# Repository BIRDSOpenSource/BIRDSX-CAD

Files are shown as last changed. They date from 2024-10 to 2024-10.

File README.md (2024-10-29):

<div align="center">
  <a href="https://lean-sat.org/opensource/">
  
  </a>
</div> 

<div align="center">
  birds x
</div>

# BIRDSX-CAD
Documentation for the structure files of the BIRDSX Satellite.

## About the BIRDSX Program:

The Mission Statement of the Project is:

> “The goal of our project is to bring diversity to the space sector and democratize the usage of space.”

The project is led by the Kyushu Institute of Technology in Japan and involves students from more than 13 countries.

Satellite Names: Dragonfly (Japan), 

Stakeholders:  Our stakeholders are the Kyushu Institute of Technology (Kyutech) and the Association for Radio Digital Communications (ARDC).

Project duration: 2023-2025

CubeSat: 2U (20x10x10) cm3

Weight: 1.758kg

Launch Date: 21st February 2025

BIRDS-X project is a 2U CubeSat dedicated to amateur radio communication.

## Organisation structure

```bash

├── BIRDSX-CAD
│   ├── Assembly Dragonfly step.zip
│   ├── Screw_Procurement list_v2 (version 1).xlsx
│   ├── Satellite part Stresses 2.xlsx
│   ├── BIRDSX- Structure
│   │   ├── CAD
│   │   │   ├── 0_2U_STD
│   │   │   ├── 1_2U_STD
│   │   │   ├── 2_2U_STD
│   │   │   ├── 3_2U_STD
│   │   │   ├── 4_2U_STD
│   │   │   ├── 5_2U_STD
│   │   │   ├── 6_2U_STD
│   │   │   ├── 7_2U_STD
│   │   │   ├── 8_2U_STD
│   │   │   ├── 9_2U_STD
│   │   ├── Drawings
│   │   │   ├── 0_2U_STD
│   │   │   ├── 1_2U_STD
│   │   │   ├── 2_2U_STD
│   │   │   ├── 3_2U_STD
│   │   │   ├── 4_2U_STD
│   │   │   ├── 5_2U_STD
│   │   │   ├── 6_2U_STD
│   │   │   ├── 7_2U_STD
│   │   │   ├── 8_2U_STD
│   │   │   ├── 9_2U_STD

```

## Features

## I like this project, can I help you?
You are welcome 🙂

* Give us a star ⭐
* Watch repository to be notified about updates 👀
* If you will find some errors, report them in Issues 🐞
* Try Birds designs on some real computer and let us know how it worked in Discussions. 💬
* We would greatly appreciate if you would also tell others about this ecosystem, it helps us to improve BIRDS Open Source. Thank you!
# BIRDSX-Source_Codes

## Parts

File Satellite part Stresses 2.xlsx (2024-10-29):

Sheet: Sheet1
Part | Material | Max Stress (Smax) (MPa) | Yield strength (MPa) | Ultimate Strength, Ftu(MPa) | MS (Yield) | MS (Ultimate) | Smax/Ftu [%] |  |  | Part | Material | Max Stress (Smax) (MPa) | Yield strength (MPa) | Ultimate Strength, Ftu(MPa) | MS (Yield) | MS (Ultimate) | Smax/Ftu [%] | Part | Material | Max Stress (Smax) (MPa) | Yield strength (MPa) | Ultimate Strength, Ftu(MPa) | MS (Yield) | MS (Ultimate) | Smax/Ftu [%]
 |  |  |  |  | 1.50 | 2.00 | <30 |  |  |  |  |  |  |  | 1.50 | 2.00 | <30 |  |  |  |  |  | 1.50 | 2.00 | <30
Structure-01 | A6061-T6 | 11.30 | 276.00 | 310.00 | 15.28 | 12.72 | 3.65 | 1.50 | 2.00 | Structure-01 | A6061-T6 | 9.76 | 276.00 | 310.00 | 17.84 | 14.87 | 3.15 | Structure-01 | A6061-T6 | 9.44 | 276.00 | 310.00 | 18.49 | 15.42 | 3.05
Structure-02 | A6061-T6 | 9.11 | 276.00 | 310.00 | 19.20 | 16.01 | 2.94 | 1.50 | 2.00 | Structure-02 | A6061-T6 | 7.86 | 276.00 | 310.00 | 22.40 | 18.71 | 2.54 | Structure-02 | A6061-T6 | 4.67 | 276.00 | 310.00 | 38.38 | 32.17 | 1.51
Structure-03 | A6061-T6 | 7.14 | 276.00 | 310.00 | 24.77 | 20.71 | 2.30 | 1.50 | 2.00 | Structure-03 | A6061-T6 | 6.32 | 276.00 | 310.00 | 28.10 | 23.51 | 2.04 | Structure-03 | A6061-T6 | 6.95 | 276.00 | 310.00 | 25.48 | 21.31 | 2.24
Structure-04 | A6061-T6 | 18.55 | 276.00 | 310.00 | 8.92 | 7.36 | 5.98 | 1.50 | 2.00 | Structure-04 | A6061-T6 | 15.20 | 276.00 | 310.00 | 11.11 | 9.20 | 4.90 | Structure-04 | A6061-T6 | 17.20 | 276.00 | 310.00 | 9.70 | 8.01 | 5.55
Structure-05 | A6061-T6 | 13.94 | 276.00 | 310.00 | 12.20 | 10.12 | 4.50 | 1.50 | 2.00 | Structure-05 | A6061-T6 | 14.63 | 276.00 | 310.00 | 11.58 | 9.59 | 4.72 | Structure-05 | A6061-T6 | 14.11 | 276.00 | 310.00 | 12.04 | 9.98 | 4.55
Structure-06 | A6061-T6 | 8.07 | 276.00 | 310.00 | 21.81 | 18.21 | 2.60 | 1.50 | 2.00 | Structure-06 | A6061-T6 | 8.81 | 276.00 | 310.00 | 19.88 | 16.59 | 2.84 | Structure-06 | A6061-T6 | 8.40 | 276.00 | 310.00 | 20.91 | 17.46 | 2.71
Structure-07 | A6061-T6 | 9.37 | 276.00 | 310.00 | 18.65 | 15.55 | 3.02 | 1.50 | 2.00 | Structure-07 | A6061-T6 | 12.08 | 276.00 | 310.00 | 14.23 | 11.83 | 3.90 | Structure-07 | A6061-T6 | 7.37 | 276.00 | 310.00 | 23.96 | 20.03 | 2.38
Structure-08 | A6061-T6 | 26.40 | 276.00 | 310.00 | 5.97 | 4.87 | 8.52 | 1.50 | 2.00 | Structure-08 | A6061-T6 | 33.20 | 276.00 | 310.00 | 4.54 | 3.67 | 10.71 | Structure-08 | A6061-T6 | 27.70 | 276.00 | 310.00 | 5.64 | 4.60 | 8.94
+Z Panel | FR4 | 1.14 | - | 270.00 | - | 117.63 | 0.42 | 1.50 | 2.00 | +Z Panel | FR4 | 1.14 | - | 270.00 | - | 117.53 | 0.42 | +Z Panel | FR4 | 1.09 | - | 270.00 | - | 123.31 | 0.40
-Z Panel | FR4 | 1.66 | - | 270.00 | - | 80.23 | 0.62 | 1.50 | 2.00 | -Z Panel | FR4 | 2.16 | - | 270.00 | - | 61.62 | 0.80 | -Z Panel | FR4 | 1.73 | - | 270.00 | - | 76.90 | 0.64
-Y/-Z Panel (Antenna 1) | FR4 | 5.15 | - | 270.00 | - | 25.22 | 1.91 | 1.50 | 2.00 | -Y/-Z Panel (Antenna 1) | FR4 | 4.89 | - | 270.00 | - | 26.58 | 1.81 | -Y/-Z Panel (Antenna 1) | FR4 | 5.17 | - | 270.00 | - | 25.09 | 1.92
-Y/+Z Panel | FR4 | 1.17 | - | 270.00 | - | 114.78 | 0.43 | 1.50 | 2.00 | -Y/+Z Panel | FR4 | 2.85 | - | 270.00 | - | 46.42 | 1.05 | -Y/+Z Panel | FR4 | 0.72 | - | 270.00 | - | 187.28 | 0.27
+Y/+Z Panel (Antenna 2) | FR4 | 1.67 | - | 270.00 | - | 79.89 | 0.62 | 1.50 | 2.00 | +Y/+Z Panel (Antenna 2) | FR4 | 1.70 | - | 270.00 | - | 78.46 | 0.63 | +Y/+Z Panel (Antenna 2) | FR4 | 1.68 | - | 270.00 | - | 79.45 | 0.62
+Y/-Z Panel | FR4 | 2.78 | - | 270.00 | - | 47.63 | 1.03 | 1.50 | 2.00 | +Y/-Z Panel | FR4 | 3.08 | - | 270.00 | - | 42.77 | 1.14 | +Y/-Z Panel | FR4 | 0.75 | - | 270.00 | - | 179.72 | 0.28
+X Panel | FR4 | 1.53 | - | 270.00 | - | 87.35 | 0.57 | 1.50 | 2.00 | +X Panel | FR4 | 1.84 | - | 270.00 | - | 72.53 | 0.68 | +X Panel | FR4 | 1.17 | - | 270.00 | - | 114.78 | 0.43
-X Panel | FR4 | 1.41 | - | 270.00 | - | 94.68 | 0.52 | 1.50 | 2.00 | -X Panel | FR4 | 3.14 | - | 270.00 | - | 42.02 | 1.16 | -X Panel | FR4 | 1.45 | - | 270.00 | - | 92.23 | 0.54
-Y Cover | FR4 | 1.09 | - | 270.00 | - | 122.51 | 0.40 | 1.50 | 2.00 | -Y Cover | FR4 | 1.12 | - | 270.00 | - | 119.00 | 0.42 | -Y Cover | FR4 | 1.10 | - | 270.00 | - | 121.95 | 0.41
+Y Cover | FR4 | 1.55 | - | 270.00 | - | 86.32 | 0.57 | 1.50 | 2.00 | +Y Cover | FR4 | 1.55 | - | 270.00 | - | 86.10 | 0.57 | +Y Cover | FR4 | 1.53 | - | 270.00 | - | 87.18 | 0.57
Component-07 | Teflon | 0.26 | - | 27.50 | - | 52.71 | 0.93 | 1.50 | 2.00 | Component-07 | Teflon | 0.27 | - | 27.50 | - | 49.74 | 0.99 | Component-07 | Teflon | 0.24 | - | 27.50 | - | 56.05 | 0.88
Component-25 | Teflon | 0.76 | - | 27.50 | - | 17.16 | 2.75 | 1.50 | 2.00 | Component-25 | Teflon | 0.94 | - | 27.50 | - | 13.57 | 3.43 | Component-25 | Teflon | 1.00 | - | 27.50 | - | 12.76 | 3.63

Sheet: Sheet2
No. | ID | Location | Type | Material | Initial Torque | Secondary Locking Feature
 |  |  |  |  | [Nm]
1-1 | ZP-1 | Plus Z panel 1 | M2 | SUS304 | 0.176 | Loctite263
1-2 | ZP-2 | Plus Z panel 2 | M2 | SUS304 | 0.176 | Loctite263
1-3 | ZP-3 | Plus Z panel 3 | M2 | SUS304 | 0.176 | Loctite263
1-4 | ZP-4 | Plus Z panel 4 | M2 | SUS304 | 0.176 | Loctite263
1-5 | ZP-5 | Plus Z panel 5 | M2 | SUS304 | 0.176 | Loctite263
1-6 | ZP-6 | Plus Z panel 6 | M2 | SUS304 | 0.176 | Loctite263
1-7 | ZP-7 | Plus Z panel 7 | M2 | SUS304 | 0.176 | Loctite263
1-8 | ZP-8 | Plus Z panel 8 | M2 | SUS304 | 0.176 | Loctite263
1-9 | ZP-9 | Plus Z panel 9 | M2 | SUS304 | 0.176 | Loctite263
1-10 | ZP-10 | Plus Z panel 10 | M2 | SUS304 | 0.176 | Loctite263
2-1 | ZM-1 | Minus Z panel 1 | M2 | SUS304 | 0.176 | Loctite263
2-2 | ZM-2 | Minus Z panel 2 | M2 | SUS304 | 0.176 | Loctite263
2-3 | ZM-3 | Minus Z panel 3 | M2 | SUS304 | 0.176 | Loctite263
2-4 | ZM-4 | Minus Z panel 4 | M2 | SUS304 | 0.176 | Loctite263
2-5 | ZM-5 | Minus Z panel 5 | M2 | SUS304 | 0.176 | Loctite263
2-6 | ZM-6 | Minus Z panel 6 | M2 | SUS304 | 0.176 | Loctite263
3-1 | XP-1 | Plus X panel 1 | M2 | SUS304 | 0.176 | Loctite263
3-2 | XP-2 | Plus X panel 2 | M2 | SUS304 | 0.176 | Loctite263
3-3 | XP-3 | Plus X panel 3 | M2 | SUS304 | 0.176 | Loctite263
3-4 | XP-4 | Plus X panel 4 | M2 | SUS304 | 0.176 | Loctite263
3-5 | XP-5 | Plus X panel 5 | M2 | SUS304 | 0.176 | Loctite263
3-6 | XP-6 | Plus X panel 6 | M2 | SUS304 | 0.176 | Loctite263
4-1 | XM-1 | Minus X panel 1 | M2 | SUS304 | 0.176 | Loctite263
4-2 | XM-2 | Minus X panel 2 | M2 | SUS304 | 0.176 | Loctite263
4-3 | XM-3 | Minus X panel 3 | M2 | SUS304 | 0.176 | Loctite263
4-4 | XM-4 | Minus X panel 4 | M2 | SUS304 | 0.176 | Loctite263
4-5 | XM-5 | Minus X panel 5 | M2 | SUS304 | 0.176 | Loctite263
4-6 | XM-6 | Minus X panel 6 | M2 | SUS304 | 0.176 | Loctite263
5-1 | YAP-1 | Plus Y (antenna) side 1 | M2 ultra-low head | SUS304 | 0.16 | Loctite263
5-2 | YAP-2 | Plus Y (antenna) side 2 | M2 ultra-low head | SUS304 | 0.16 | Loctite263
5-3 | YAP-3 | Plus Y (antenna) side 3 | M2 ultra-low head | SUS304 | 0.16 | Loctite263
5-4 | YAP-4 | Plus Y (antenna) side 4 | M2 ultra-low head | SUS304 | 0.16 | Loctite263
5-5 | YAP-5 | Plus Y (antenna) side 5 (Heat cutter) | M2 | SUS304 | 0.176 | Loctite263
5-6 | YAP-6 | Plus Y (antenna) side 6 (Heat cutter) | M2 | SUS304 | 0.176 | Loctite263
6-1 | YMP-1 | Plus Y (Mechanism) side 1 | M2 | SUS304 | 0.176 | Loctite263
6-2 | YMP-2 | Plus Y (Mechanism) side 2 | M2 | SUS304 | 0.176 | Loctite263
6-3 | YMP-3 | Plus Y (Mechanism) side 3 | M2 | SUS304 | 0.176 | Loctite263
6-4 | YMP-4 | Plus Y (Mechanism) side 4 | M2 | SUS304 | 0.176 | Loctite263
6-5 | YMP-5 | Plus Y (Mechanism) side 5 (Antenna holder) | M2 | SUS304 | 0.176 | Loctite263
6-6 | YMP-6 | Plus Y (Mechanism) side 6 (Antenna holder) | M2 | SUS304 | 0.176 | Loctite263
6-7 | YMP-7 | Plus Y (Mechanism) side 7 (Antenna holder) | M2 | SUS304 | 0.176 | Loctite263
6-8 | YMP-8 | Plus Y (Mechanism) side 8 (Antenna holder) | M2 | SUS304 | 0.176 | Loctite263
6-9 | YMP-9 | Plus Y (Mechanism) side 9 (Antenna holder) | M2 | SUS304 | 0.176 | Loctite263
6-10 | YMP-10 | Plus Y (Mechanism) side 10 (Antenna holder) | M2 | SUS304 | 0.176 | Loctite263
6-11 | YMP-11 | Plus Y (Mechanism) side 11 (Antenna holder) | M2 | SUS304 | 0.176 | Loctite263
6-12 | YMP-12 | Plus Y (Mechanism) side 12 (Antenna holder) | M2 | SUS304 | 0.176 | Loctite263
7-1 | YP-1 | Plus Y side 1 | M2 | SUS304 | 0.176 | Loctite263
7-2 | YP-2 | Plus Y side 2 | M2 | SUS304 | 0.176 | Loctite263
7-3 | YP-3 | Plus Y side 3 | M2 | SUS304 | 0.176 | Loctite263
7-4 | YP-4 | Plus Y side 4 | M2 | SUS304 | 0.176 | Loctite263
8-1 | YCP-1 | Plus Y (Cover) side 1 | M2 ultra-low head | SUS304 | 0.16 | Loctite263
8-2 | YCP-2 | Plus Y (Cover) side 2 | M2 ultra-low head | SUS304 | 0.16 | Loctite263
9-1 | YAM-1 | Minus Y (antenna) side 1 | M2 ultra-low head | SUS304 | 0.16 | Loctite263
9-2 | YAM-2 | Minus Y (antenna) side 2 | M2 ultra-low head | SUS304 | 0.16 | Loctite263
9-3 | YAM-3 | Minus Y (antenna) side 3 | M2 ultra-low head | SUS304 | 0.16 | Loctite263
9-4 | YAM-4 | Minus Y (antenna) side 4 | M2 ultra-low head | SUS304 | 0.16 | Loctite263
9-5 | YAM-5 | Minus Y (antenna) side 5 (Heat cutter) | M2 | SUS304 | 0.176 | Loctite263
9-6 | YAM-6 | Minus Y (antenna) side 6 (Heat cutter) | M2 | SUS304 | 0.176 | Loctite263
10-1 | YMM-1 | Minus Y (Mechanism) side 1 | M2 | SUS304 | 0.176 | Loctite263
10-2 | YMM-2 | Minus Y (Mechanism) side 2 | M2 | SUS304 | 0.176 | Loctite263
10-3 | YMM-3 | Minus Y (Mechanism) side 3 | M2 | SUS304 | 0.176 | Loctite263
10-4 | YMM-4 | Minus Y (Mechanism) side 4 | M2 | SUS304 | 0.176 | Loctite263
10-5 | YMM-5 | Plus Y (Mechanism) side 5 (Antenna holder) | M2 | SUS304 | 0.176 | Loctite263
10-6 | YMM-6 | Plus Y (Mechanism) side 6 (Antenna holder) | M2 | SUS304 | 0.176 | Loctite263
10-7 | YMM-7 | Plus Y (Mechanism) side 7 (Antenna holder) | M2 | SUS304 | 0.176 | Loctite263
10-8 | YMM-8 | Plus Y (Mechanism) side 8 (Antenna holder) | M2 | SUS304 | 0.176 | Loctite263
10-9 | YMM-9 | Plus Y (Mechanism) side 9 (Antenna holder) | M2 | SUS304 | 0.176 | Loctite263
10-10 | YMM-10 | Plus Y (Mechanism) side 10 (Antenna holder) | M2 | SUS304 | 0.176 | Loctite263
10-11 | YMM-11 | Plus Y (Mechanism) side 11 (Antenna holder) | M2 | SUS304 | 0.176 | Loctite263
10-12 | YMM-12 | Plus Y (Mechanism) side 12 (Antenna holder) | M2 | SUS304 | 0.176 | Loctite263
11-1 | YM-1 | Minus Y side 1 | M2 | SUS304 | 0.176 | Loctite263
11-2 | YM-2 | Minus Y side 2 | M2 | SUS304 | 0.176 | Loctite263
11-3 | YM-3 | Minus Y side 3 | M2 | SUS304 | 0.176 | Loctite263
11-4 | YM-4 | Minus Y side 4 | M2 | SUS304 | 0.176 | Loctite263
12-1 | YCM-1 | Minus Y (Cover) side 1 | M2 | SUS304 | 0.160 | Loctite263
12-2 | YCM-2 | Minus Y (Cover) side 2 | M2 | SUS304 | 0.160 | Loctite263
13-1 | MS-1 | Structure 1 | M2 | SUS304 | 0.176 | Loctite263
13-2 | MS-2 | Structure 2 | M2 | SUS304 | 0.176 | Loctite263
13-3 | MS-3 | Structure 3 | M2 | SUS304 | 0.176 | Loctite263
13-4 | MS-4 | Structure 4 | M2 | SUS304 | 0.176 | Loctite263
13-5 | MS-5 | Structure 5 | M2 | SUS304 | 0.176 | Loctite263
13-6 | MS-6 | Structure 6 | M2 | SUS304 | 0.176 | Loctite263
13-7 | MS-7 | Structure 7 | M2 | SUS304 | 0.176 | Loctite263
13-8 | MS-8 | Structure 8 | M2 | SUS304 | 0.176 | Loctite263
13-9 | MS-9 | Structure 9 | M2 | SUS304 | 0.176 | Loctite263
13-10 | MS-10 | Structure 10 | M2 | SUS304 | 0.176 | Loctite263
13-11 | MS-11 | Structure 11 | M2 | SUS304 | 0.176 | Loctite263
13-12 | MS-12 | Structure 12 | M2 | SUS304 | 0.176 | Loctite263
13-13 | MS-13 | Structure 13 | M2 | SUS304 | 0.176 | Loctite263
14-1 | DS-1 | Deployment Switch 1 | M1.6 | SUS304 | 0.086 | Loctite263
14-2 | DS-2 | Deployment Switch 2 | M1.6 | SUS304 | 0.086 | Loctite263
14-3 | DS-3 | Deployment Switch 3 | M1.6 | SUS304 | 0.086 | Loctite263

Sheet: Sheet3
No. | Group Name | Pre-load Stress | External Stress | Ultimate Strength [MPa] | MS (FS=2) | Screw No. with Max Stress (Table 5.3.3-2) | NDE Required? | No. | Group Name | Pre-load Stress | External Stress | Ultimate Strength [MPa] | MS (FS=2) | Screw No. with Max Stress (Table 5.3.3-2) | NDE Required? | No. | Group Name | Pre-load Stress | External Stress | Ultimate Strength [MPa] | MS (FS=2) | Screw No. with Max Stress (Table 5.3.3-2) | NDE Required?
 |  | [MPa] | [MPa] |  |  |  |  |  |  | [MPa] | [MPa] |  |  |  |  |  |  | [MPa] | [MPa]
1.00 | Bolt: | 213.00 | 15.09 | 505.00 | 1.08 | 3-6 | No | 1.00 | Bolt: | 213.00 | 18.90 | 505.00 | 1.01 | 3-4 | No | 1.00 | Bolt: | 213.00 | 9.37 | 505.00 | 1.18 | 3-4 | No
 | +X panel |  |  |  |  |  |  |  | +X panel |  |  |  |  |  |  |  | +X panel
2.00 | Bolt: | 213.00 | 14.76 | 505.00 | 1.08 | 4-6 | No | 2.00 | Bolt: | 213.00 | 45.43 | 505.00 | 0.66 | 4-5 | No | 2.00 | Bolt: | 213.00 | 16.04 | 505.00 | 1.06 | 4-3 | No
 | -X panel |  |  |  |  |  |  |  | -X panel |  |  |  |  |  |  |  | -X panel
3.00 | Bolt: | 213.00 | 40.87 | 505.00 | 0.71 | 7-3 | No | 3.00 | Bolt: | 213.00 | 18.78 | 505.00 | 1.02 | 7-2 | No | 3.00 | Bolt: | 213.00 | 13.32 | 505.00 | 1.11 | 7-4 | No
 | +Y panel |  |  |  |  |  |  |  | +Y panel |  |  |  |  |  |  |  | +Y panel
4.00 | Bolt: | 193.00 | 41.67 | 505.00 | 0.83 | 5-1 | No | 4.00 | Bolt: | 193.00 | 16.29 | 505.00 | 1.24 | 5-4 | No | 4.00 | Bolt: | 193.00 | 16.57 | 505.00 | 1.23 | 5-4 | No
 | +Y Antenna Panel |  |  |  |  |  |  |  | +Y Antenna Panel |  |  |  |  |  |  |  | +Y Antenna Panel
5.00 | Bolt: | 213.00 | 33.07 | 505.00 | 0.81 | 6-1 | No | 5.00 | Bolt: | 213.00 | 33.09 | 505.00 | 0.81 | 6-1 | No | 5.00 | Bolt: | 213.00 | 33.15 | 505.00 | 0.81 | 6-1 | No
 | +Y Mechanism |  |  |  |  |  |  |  | +Y Mechanism |  |  |  |  |  |  |  | +Y Mechanism
6.00 | Bolt: | 193.00 | 29.89 | 505.00 | 1.00 | 8-2 | No | 6.00 | Bolt: | 193.00 | 30.13 | 505.00 | 0.99 | 8-2 | No | 6.00 | Bolt: | 193.00 | 29.78 | 505.00 | 1.00 | 8-2 | No
 | +Y Cover |  |  |  |  |  |  |  | +Y Cover |  |  |  |  |  |  |  | +Y Cover
7.00 | Bolt: | 213.00 | 17.33 | 505.00 | 1.04 | 11-2 | No | 7.00 | Bolt: | 213.00 | 14.46 | 505.00 | 1.09 | 11-2 | No | 7.00 | Bolt: | 213.00 | 13.84 | 505.00 | 1.10 | 11-2 | No
 | -Y panel |  |  |  |  |  |  |  | -Y panel |  |  |  |  |  |  |  | -Y panel
8.00 | Bolt: | 193.00 | 77.53 | 505.00 | 0.45 | 9-4 | No | 8.00 | Bolt: | 193.00 | 40.42 | 505.00 | 0.84 | 9-1 | No | 8.00 | Bolt: | 193.00 | 17.09 | 505.00 | 1.22 | 9-2 | No
 | -Y Antenna Panel |  |  |  |  |  |  |  | -Y Antenna Panel |  |  |  |  |  |  |  | -Y Antenna Panel
9.00 | Bolt: | 213.00 | 45.65 | 505.00 | 0.66 | 10-4 | No | 9.00 | Bolt: | 213.00 | 47.49 | 505.00 | 0.64 | 10-3 | No | 9.00 | Bolt: | 213.00 | 43.47 | 505.00 | 0.68 | 10-3 | No
 | -Y Mechanism |  |  |  |  |  |  |  | -Y Mechanism |  |  |  |  |  |  |  | -Y Mechanism
10.00 | Bolt: | 193.00 | 25.08 | 505.00 | 1.08 | 12-2 | No | 10.00 | Bolt: | 193.00 | 25.18 | 505.00 | 1.08 | 12-2 | No | 10.00 | Bolt: | 193.00 | 25.02 | 505.00 | 1.08 | 12-2 | No
 | -Y Cover |  |  |  |  |  |  |  | -Y Cover |  |  |  |  |  |  |  | -Y Cover
11.00 | Bolt: | 213.00 | 7.54 | 505.00 | 1.21 | 1-2 | No | 11.00 | Bolt: | 213.00 | 8.02 | 505.00 | 1.20 | 1-10 | No | 11.00 | Bolt: | 213.00 | 7.69 | 505.00 | 1.21 | 1-4 | No
 | +Z panel |  |  |  |  |  |  |  | +Z panel |  |  |  |  |  |  |  | +Z panel
12.00 | Bolt: | 213.00 | 12.22 | 505.00 | 1.13 | 2-4 | No | 12.00 | Bolt: | 213.00 | 11.87 | 505.00 | 1.13 | 2-6 | No | 12.00 | Bolt: | 213.00 | 11.82 | 505.00 | 1.13 | 2-4 | No
 | -Z panel |  |  |  |  |  |  |  | -Z panel |  |  |  |  |  |  |  | -Z panel
13.00 | Main Structure | 213.00 | 93.71 | 505.00 | 0.26 | 13-8 | No | 13.00 | Main Structure | 213.00 | 132.88 | 505.00 | 0.05 | 13-6 | No | 13.00 | Main Structure | 213.00 | 83.59 | 505.00 | 0.33 | 13-6 | No
14.00 | Deployment Switch | 211.00 | 64.47 | 505.00 | 0.49 | 14-3 | No | 13.00 | Deployment Switch | 211.00 | 64.75 | 505.00 | 0.48 | 14-3 | No | 13.00 | Deployment Switch | 211.00 | 64.99 | 505.00 | 0.48 | 14-3 | No

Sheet: Sheet4
No. | Group Name | Pre-load Stress | External Stress | Ultimate Strength [MPa] | MS (FS=1) | Screw No. with Max Stress (Table 5.3.3-2) | Removed Screw No. | NDE Required? | No. | Group Name | Pre-load Stress | External Stress | Ultimate Strength [MPa] | MS (FS=1) | Screw No. with Max Stress (Table 5.3.3-2) | Removed Screw No. | NDE Required? | No. | Group Name | Pre-load Stress | External Stress | Ultimate Strength [MPa] | MS (FS=2) | Screw No. with Max Stress (Table 5.3.3-2) | Removed Screw No. | NDE Required?
 |  | [MPa] | [MPa] |  |  |  | (Table 5.3.3-2) |  |  |  | [MPa] | [MPa] |  |  |  | (Table 5.3.3-2) |  |  |  | [MPa] | [MPa] |  |  |  | (Table 5.3.3-2)
1.00 | Bolt: | 213.00 | 15.72 | 505.00 | 1.21 | 3-3 | 3-6 | No | 1.00 | Bolt: | 213.00 | 19.10 | 505.00 | 1.18 | 3-5 | 3-4 | No | 1.00 | Bolt: | 213.00 | 10.62 | 505.00 | 1.26 | 3-5 | 3-4 | No
 | +X panel |  |  |  |  |  |  |  |  | +X panel |  |  |  |  |  |  |  |  | +X panel
2.00 | Bolt: | 213.00 | 21.99 | 505.00 | 1.15 | 4-4 | 4-6 | No | 2.00 | Bolt: | 213.00 | 56.92 | 505.00 | 0.87 | 4-4 | 4-5 | No | 2.00 | Bolt: | 213.00 | 18.38 | 505.00 | 1.18 | 4-4 | 4-3 | No
 | -X panel |  |  |  |  |  |  |  |  | -X panel |  |  |  |  |  |  |  |  | -X panel
3.00 | Bolt: | 213.00 | 58.20 | 505.00 | 0.86 | 7-2 | 7-3 | No | 3.00 | Bolt: | 213.00 | 16.55 | 505.00 | 1.20 | 7-1 | 7-2 | No | 3.00 | Bolt: | 213.00 | 17.14 | 505.00 | 1.19 | 7-1 | 7-4 | No
 | +Y panel |  |  |  |  |  |  |  |  | +Y panel |  |  |  |  |  |  |  |  | +Y panel
4.00 | Bolt: | 193.00 | 78.65 | 505.00 | 0.86 | 5-4 | 5-1 | No | 4.00 | Bolt: | 193.00 | 18.68 | 505.00 | 1.39 | 5-2 | 5-4 | No | 4.00 | Bolt: | 193.00 | 19.14 | 505.00 | 1.38 | 5-1 | 5-4 | No
 | +Y Antenna Panel |  |  |  |  |  |  |  |  | +Y Antenna Panel |  |  |  |  |  |  |  |  | +Y Antenna Panel
5.00 | Bolt: | 213.00 | 37.10 | 505.00 | 1.02 | 6-3 | 6-1 | No | 5.00 | Bolt: | 213.00 | 37.12 | 505.00 | 1.02 | 6-3 | 6-1 | No | 5.00 | Bolt: | 213.00 | 37.17 | 505.00 | 1.02 | 6-3 | 6-1 | No
 | +Y Mechanism |  |  |  |  |  |  |  |  | +Y Mechanism |  |  |  |  |  |  |  |  | +Y Mechanism
6.00 | Bolt: | 193.00 | 41.40 | 505.00 | 1.15 | 8-1 | 8-2 | No | 6.00 | Bolt: | 193.00 | 41.90 | 505.00 | 1.15 | 8-1 | 8-2 | No | 6.00 | Bolt: | 193.00 | 41.99 | 505.00 | 1.15 | 8-1 | 8-2 | No
 | +Y Cover |  |  |  |  |  |  |  |  | +Y Cover |  |  |  |  |  |  |  |  | +Y Cover
7.00 | Bolt: | 213.00 | 23.81 | 505.00 | 1.13 | 11-1 | 11-2 | No | 7.00 | Bolt: | 213.00 | 17.25 | 505.00 | 1.19 | 11-1 | 11-2 | No | 7.00 | Bolt: | 213.00 | 16.16 | 505.00 | 1.20 | 11-1 | 11-2 | No
 | -Y panel |  |  |  |  |  |  |  |  | -Y panel |  |  |  |  |  |  |  |  | -Y panel
8.00 | Bolt: | 193.00 | 87.77 | 505.00 | 0.80 | 9-3 | 9-4 | No | 8.00 | Bolt: | 193.00 | 32.83 | 505.00 | 1.24 | 9-2 | 9-1 | No | 8.00 | Bolt: | 193.00 | 22.00 | 505.00 | 1.35 | 9-3 | 9-2 | No
 | -Y Antenna Panel |  |  |  |  |  |  |  |  | -Y Antenna Panel |  |  |  |  |  |  |  |  | -Y Antenna Panel
9.00 | Bolt: | 213.00 | 81.75 | 505.00 | 0.71 | 10-3 | 10-4 | No | 9.00 | Bolt: | 213.00 | 75.36 | 505.00 | 0.75 | 10-4 | 10-3 | No | 9.00 | Bolt: | 213.00 | 60.79 | 505.00 | 0.84 | 10-4 | 10-3 | No
 | -Y Mechanism |  |  |  |  |  |  |  |  | -Y Mechanism |  |  |  |  |  |  |  |  | -Y Mechanism
10.00 | Bolt: | 193.00 | 32.37 | 505.00 | 1.24 | 12-1 | 12-2 | No | 10.00 | Bolt: | 193.00 | 32.47 | 505.00 | 1.24 | 12-1 | 12-2 | No | 10.00 | Bolt: | 193.00 | 32.90 | 505.00 | 1.24 | 12-1 | 12-2 | No
 | -Y Cover |  |  |  |  |  |  |  |  | -Y Cover |  |  |  |  |  |  |  |  | -Y Cover
11.00 | Bolt: | 213.00 | 8.23 | 505.00 | 1.28 | 1-4 | 1-2 | No | 11.00 | Bolt: | 213.00 | 8.36 | 505.00 | 1.28 | 1-4 | 1-10 | No | 11.00 | Bolt: | 213.00 | 7.99 | 505.00 | 1.29 | 1-3 | 1-4 | No
 | +Z panel |  |  |  |  |  |  |  |  | +Z panel |  |  |  |  |  |  |  |  | +Z panel
12.00 | Bolt: | 213.00 | 14.83 | 505.00 | 1.22 | 2-6 | 2-4 | No | 12.00 | Bolt: | 213.00 | 13.99 | 505.00 | 1.22 | 2-4 | 2-6 | No | 12.00 | Bolt: | 213.00 | 14.30 | 505.00 | 1.22 | 2-6 | 2-4 | No
 | -Z panel |  |  |  |  |  |  |  |  | -Z panel |  |  |  |  |  |  |  |  | -Z panel
13.00 | Main Structure | 213.00 | 218.36 | 505.00 | 0.17 | 13-11 | 13-8 | No | 13.00 | Main Structure | 213.00 | 137.97 | 505.00 | 0.44 | 13-11 | 13-6 | No | 13.00 | Main Structure | 213.00 | 89.25 | 505.00 | 0.67 | 13-5 | 13-6 | No
14.00 | Deployment Switch | 211.00 | 64.37 | 505.00 | 0.83 | 14-3 | - | No | 14.00 | Deployment Switch | 211.00 | 64.77 | 505.00 | 0.83 | 14-3 | - | No | 14.00 | Deployment Switch | 211.00 | 65.12 | 505.00 | 0.83 | 14-3 | - | No

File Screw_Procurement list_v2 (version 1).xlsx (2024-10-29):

No. | Type | Part No | Length(mm) | Bit size (mm) | Material | Qty. EM | Qty. FM | Spare | total | Vendor | Purpose | URL
1
2
3
4
5
6 | Screw | SNSS M1.6-6 |  |  |  |  | 3 |  | 8 | NBK | Dep SW
7 | Nut | SLBNR3 |  |  | SUS304相当 |  | 4 |  | 8 | MISUMI | Rods | https://jp.misumi-ec.com/vona2/detail/110300250540/?HissuCode=SLBNR3&gad_source=1&gclsrc=aw.ds
9 | Screw | SNSS-M2-6-SD | 6 | 1.5 | SUSXM7 (equivalent withSUS304) | 20 | 20 |  |  | NBK | BPB | https://jp.misumi-ec.com/vona2/detail/221006493827/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
13 | Screw | CBSTSR2-6 | 6 | 1.3 | equivalent with SUS304 | 20 | 12 |  |  | MISUMI | External (antenna panel) | https://jp.misumi-ec.com/vona2/detail/110302280540/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
16 | Screw | SCB2-12 | 10 | 1.5 | SUSXM7 (equivalent withSUS304) | 11 | 11 |  | 20 | MISUMI | Main Structure | https://jp.misumi-ec.com/vona2/detail/110300239250/?list=PageCategory
20 | Screw | SCB2-4 | 4 | 1.5 | SUSXM7 (equivalent withSUS304) | 2 | 2 |  |  | MISUMI | Main Structure | https://jp.misumi-ec.com/vona2/detail/110300239250/?list=PageCategory
21 | Screw | SCB2-6 | 6 | 1.5 | SUSXM7 (equivalent withSUS304) | 28 | 28 |  | 30 | MISUMI | External (solar panel) | https://jp.misumi-ec.com/vona2/detail/110300239250/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
22 | Spacer 4.5 | FWSJW-D6-V4-T4.5 |  |  | MC Nylon |  | 4 |  | 10 | Hirosugi-Keiki | Spacer | https://jp.misumi-ec.com/vona2/detail/110300235320/?list=PageCategory
23 | Spacer 19.15 | FCLJW-V4-D6-L19.5 |  |  | MC Nylon |  | 4 |  | 10 | MISUMI | Spacer | https://jp.misumi-ec.com/vona2/detail/110300236270/?list=PageCategory
24 | Spacer 6.5 | FWSJW-D6-V4-T6.5 |  |  | MC Nylon |  | 4 |  | 10 | Hirosugi-Keiki | Spacer | https://jp.misumi-ec.com/vona2/detail/110300235320/?list=PageCategory
17 | Spacer 5.4 | FWSJW-D6-V4-T5.5 |  |  | MC Nylon |  | 4 |  | 10 | MISUMI | Spacer | https://jp.misumi-ec.com/vona2/detail/110300235320/?list=PageCategory
14 | Spacer 14.4 | FCLJW-V4-D6-L14.5 |  |  | MC Nylon |  | 24 |  | 40 | MISUMI | Spacer | https://jp.misumi-ec.com/vona2/detail/110300236270/?list=PageCategory
15 | Spacer 5.9, 5.75 | FWSJW-D6-V4-T6 |  |  | MC Nylon |  | 8 |  | 20 | MISUMI | Spacer | https://jp.misumi-ec.com/vona2/detail/110300235320/?list=PageCategory
12 | Spacer 15.2 | FCLJW-V4-D6-L15.5 |  |  | MC Nylon |  | 4 |  | 10 | MISUMI | Spacer | https://jp.misumi-ec.com/vona2/detail/110300236270/?list=PageCategory

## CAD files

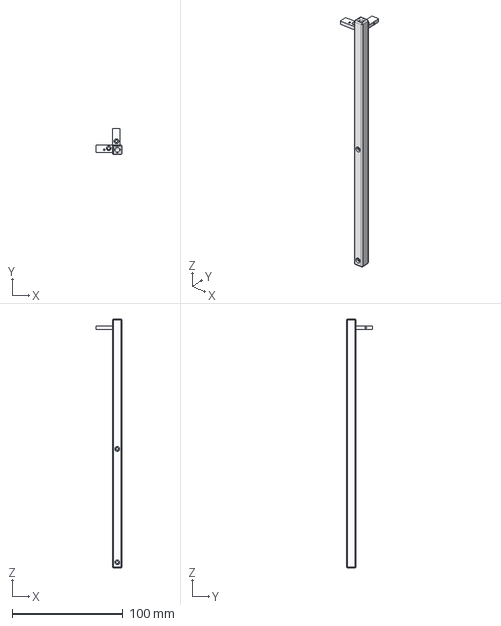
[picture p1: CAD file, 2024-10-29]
BIRDSX-Structure/CAD/8_2U_STD.step
23.5 x 23.5 x 225.0 mm

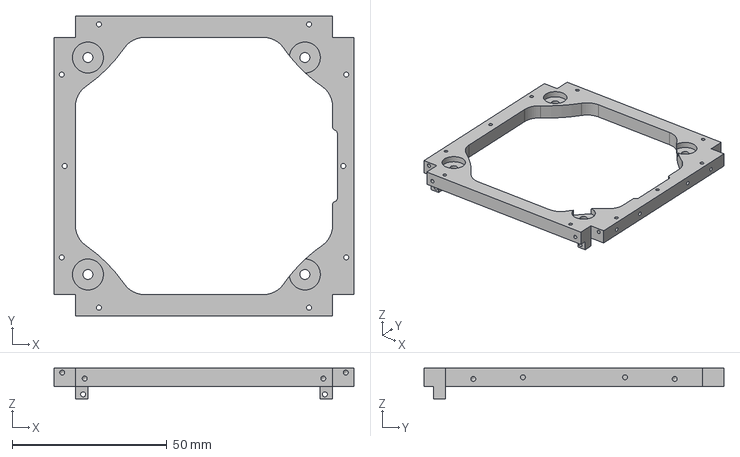
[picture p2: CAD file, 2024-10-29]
BIRDSX-Structure/CAD/4_2U_STD.step
96.8 x 96.8 x 10.0 mm

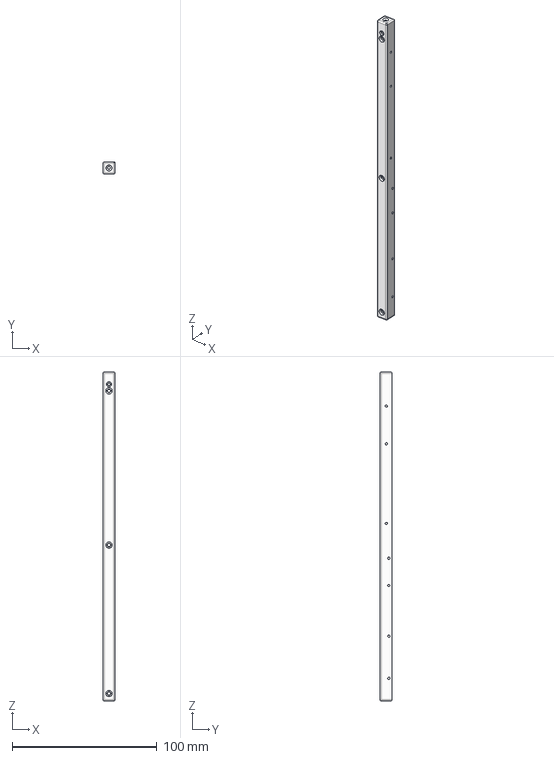
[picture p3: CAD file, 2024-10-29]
BIRDSX-Structure/CAD/5_2U_STD.step
8.50 x 8.50 x 227.0 mm

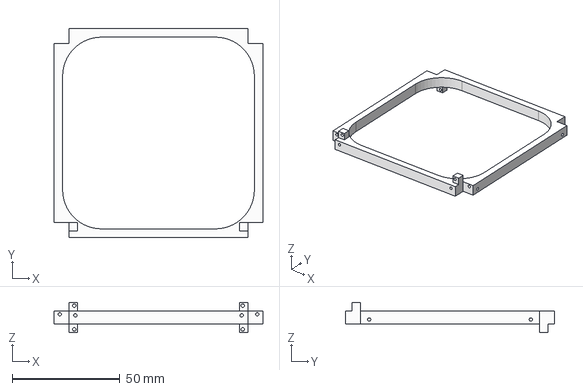
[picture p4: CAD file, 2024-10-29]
BIRDSX-Structure/CAD/3_2U_STD.step
96.8 x 96.8 x 14.0 mm

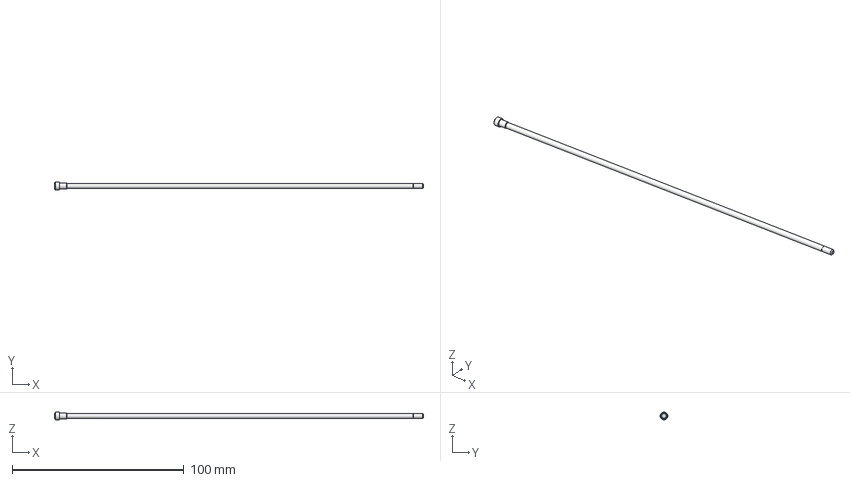
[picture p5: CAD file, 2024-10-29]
BIRDSX-Structure/CAD/9_2U_STD.step
214.8 x 4.50 x 4.50 mm

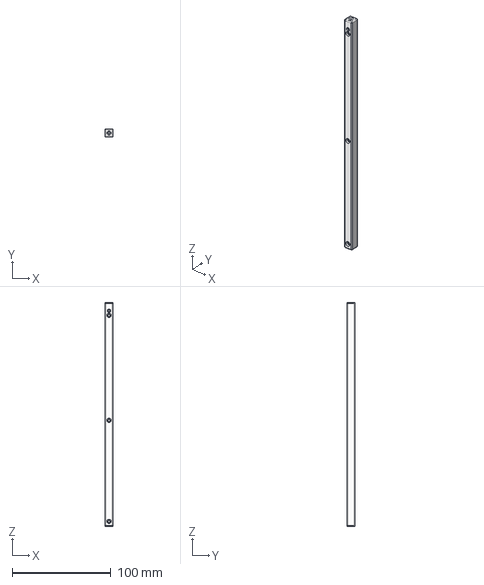
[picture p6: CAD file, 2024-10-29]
BIRDSX-Structure/CAD/6_2U_STD.step
8.50 x 8.50 x 227.0 mm

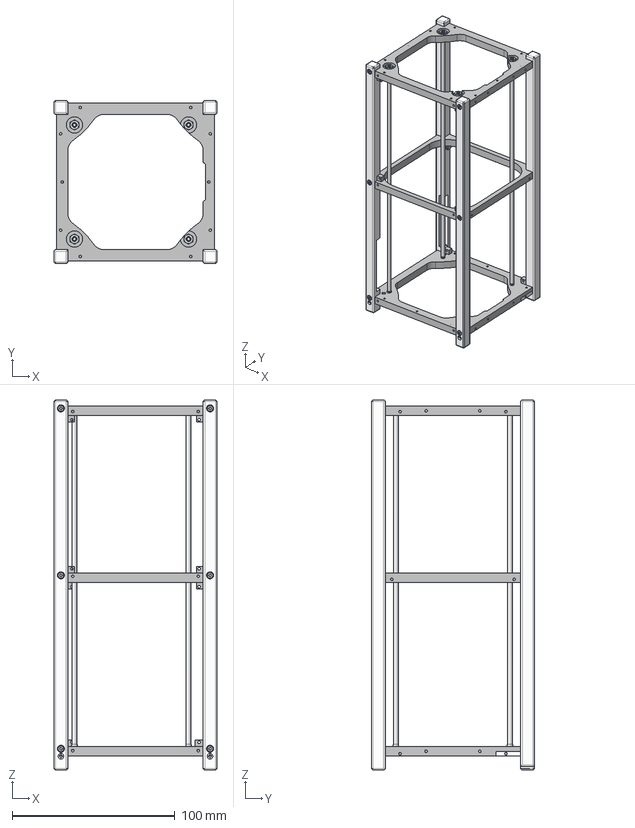
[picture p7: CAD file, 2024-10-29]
BIRDSX-Structure/CAD/1_2U_STD.step
100.0 x 100.0 x 227.0 mm
FM_RAIL(-Y/-X)_deployment_switch
FM_RAIL(-Y/+X)_deployment_switch
FM_RAIL(+Y/+X)_spring_plunger
FM_RAIL(+Y/-X)_deployment_switch
FM_FRAME BIRDS-X_-Z
FM_FRAME BIRDS-X_+Z
FM_FRAME BIRDS-X_0Z
SCB2-12 x 11
SCB2-4 x 2
Rod New x 4
FM_SLBNR3 x 4

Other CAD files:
BIRDSX-Structure/CAD/2_2U_STD.step
BIRDSX-Structure/CAD/7_2U_STD.step
BIRDSX-Structure/CAD/0_2U_STD.step

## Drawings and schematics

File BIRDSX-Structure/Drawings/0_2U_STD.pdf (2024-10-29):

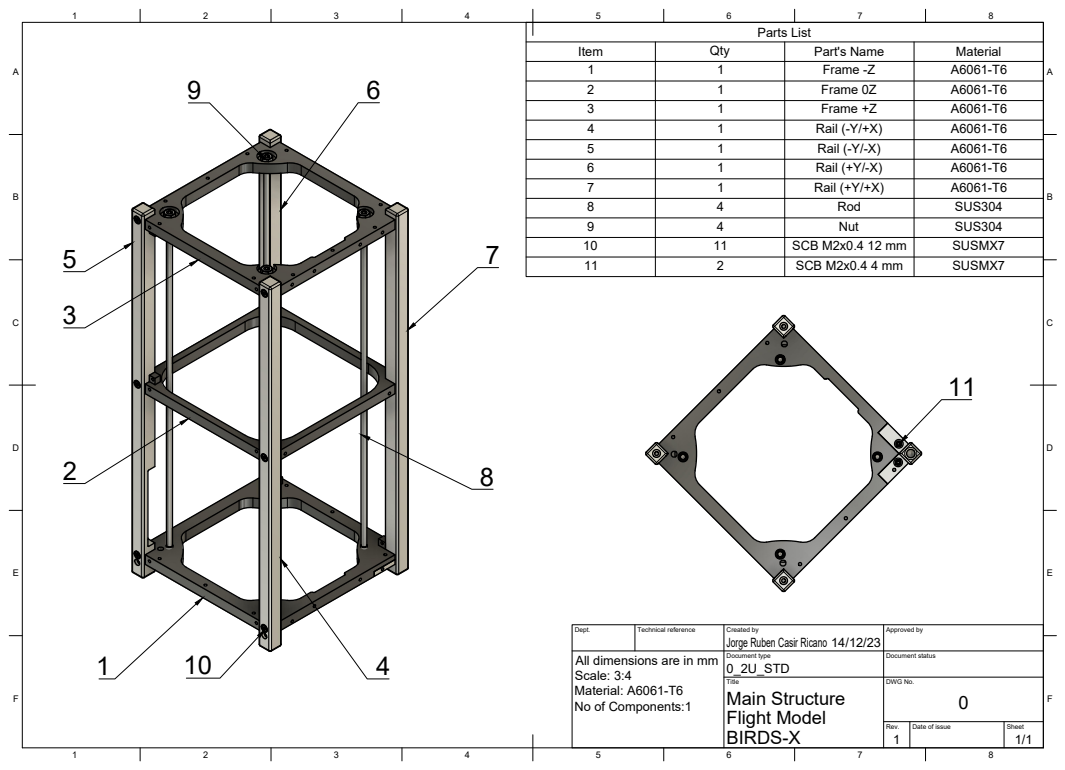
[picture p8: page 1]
Title; DWG No.; Rev.; Date of issue; Sheet; Flight Model; Main Structure; Parts List

Item | Qty | Part's Name | Material
1 | 1 | Frame -Z | A6061-T6
2 | 1 | Frame 0Z | A6061-T6
3 | 1 | Frame +Z | A6061-T6
4 | 1 | Rail (-Y/+X) | A6061-T6
5 | 1 | Rail (-Y/-X) | A6061-T6
6 | 1 | Rail (+Y/-X) | A6061-T6
7 | 1 | Rail (+Y/+X) | A6061-T6
8 | 4 | Rod | SUS304
9 | 4 | Nut | SUS304
10 | 11 | SCB M2x0.4 12 mm | SUSMX7
11 | 2 | SCB M2x0.4 4 mm | SUSMX7

Dept. | Technical reference | Created by Jorge Ruben Casir Ricano 14/12/23 | Approved by

All dimensions are in mm
Scale: 3:4
Material: A6061-T6
No of Components:1

Document type 0_2U_STD | Document status

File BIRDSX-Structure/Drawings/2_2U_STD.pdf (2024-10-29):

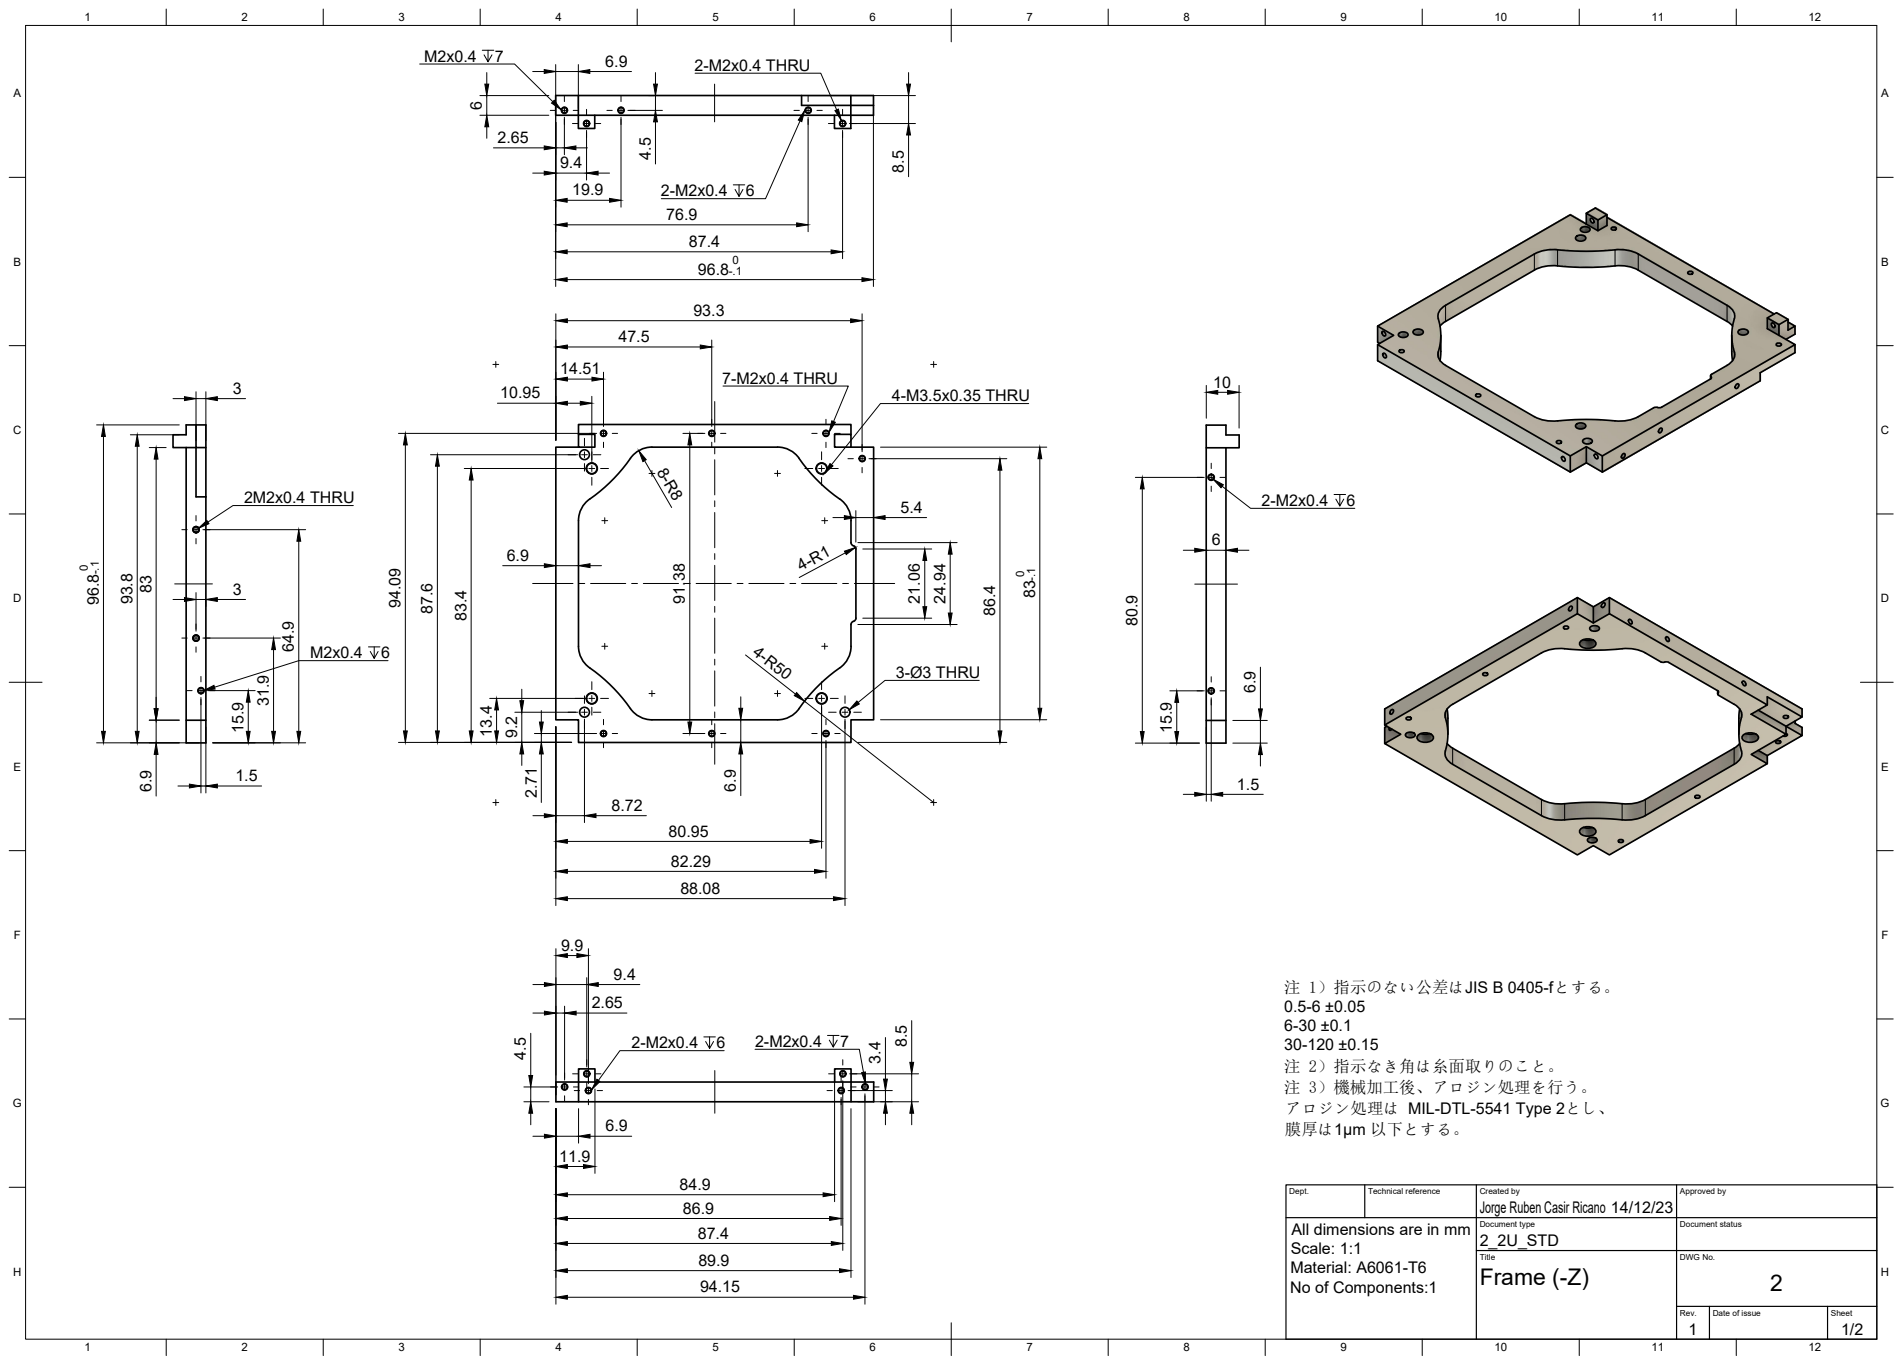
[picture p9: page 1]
Jorge Ruben Casir Ricano 83 96.8 0-.1; 7-M2x0.4 THRU; 4-M3.5x0.35 THRU; 3-Ø3 THRU; 2-M2x0.4 THRU; 注 1）指示のない公差はJIS B 0405-fとする。 0.5-6 ±0.05 6-30 ±0.1 30-120 ±0.15 注 2）指示なき角は糸面取りのこと。 注 3）機械加工後、アロジン処理を行う。 アロジン処理は MIL-DTL-5541 Type 2とし、; 膜厚は1μm 以下とする。 83 0-.1; 2M2x0.4 THRU

Dept. | Technical reference | Created by 14/12/23 | Approved by

All dimensions are in mm Scale: 1:1 Material: A6061-T6 No of Components:1 | | Document type 2_2U_STD | Document status

Title Frame (-Z) | DWG No. 2

Rev. 1 | Date of issue | Sheet 1/2

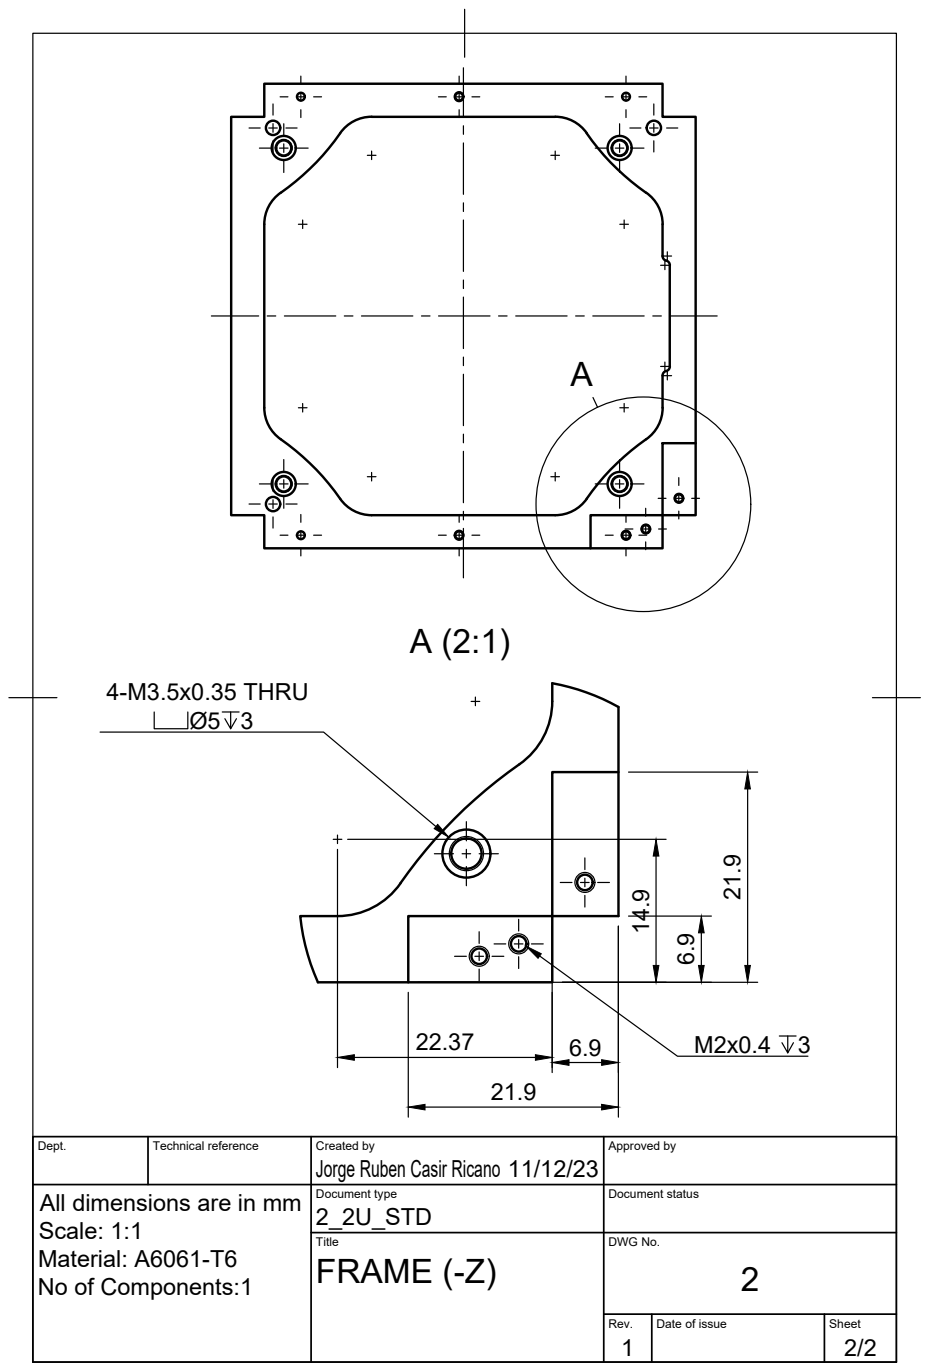
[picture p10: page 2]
4-M3.5x0.35 THRU Ø5 3

Dept. | Technical reference | Created by Jorge Ruben Casir Ricano 11/12/23 | Approved by

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

Title FRAME (-Z) | DWG No. 2

Rev. 1 | Date of issue | Sheet 2/2

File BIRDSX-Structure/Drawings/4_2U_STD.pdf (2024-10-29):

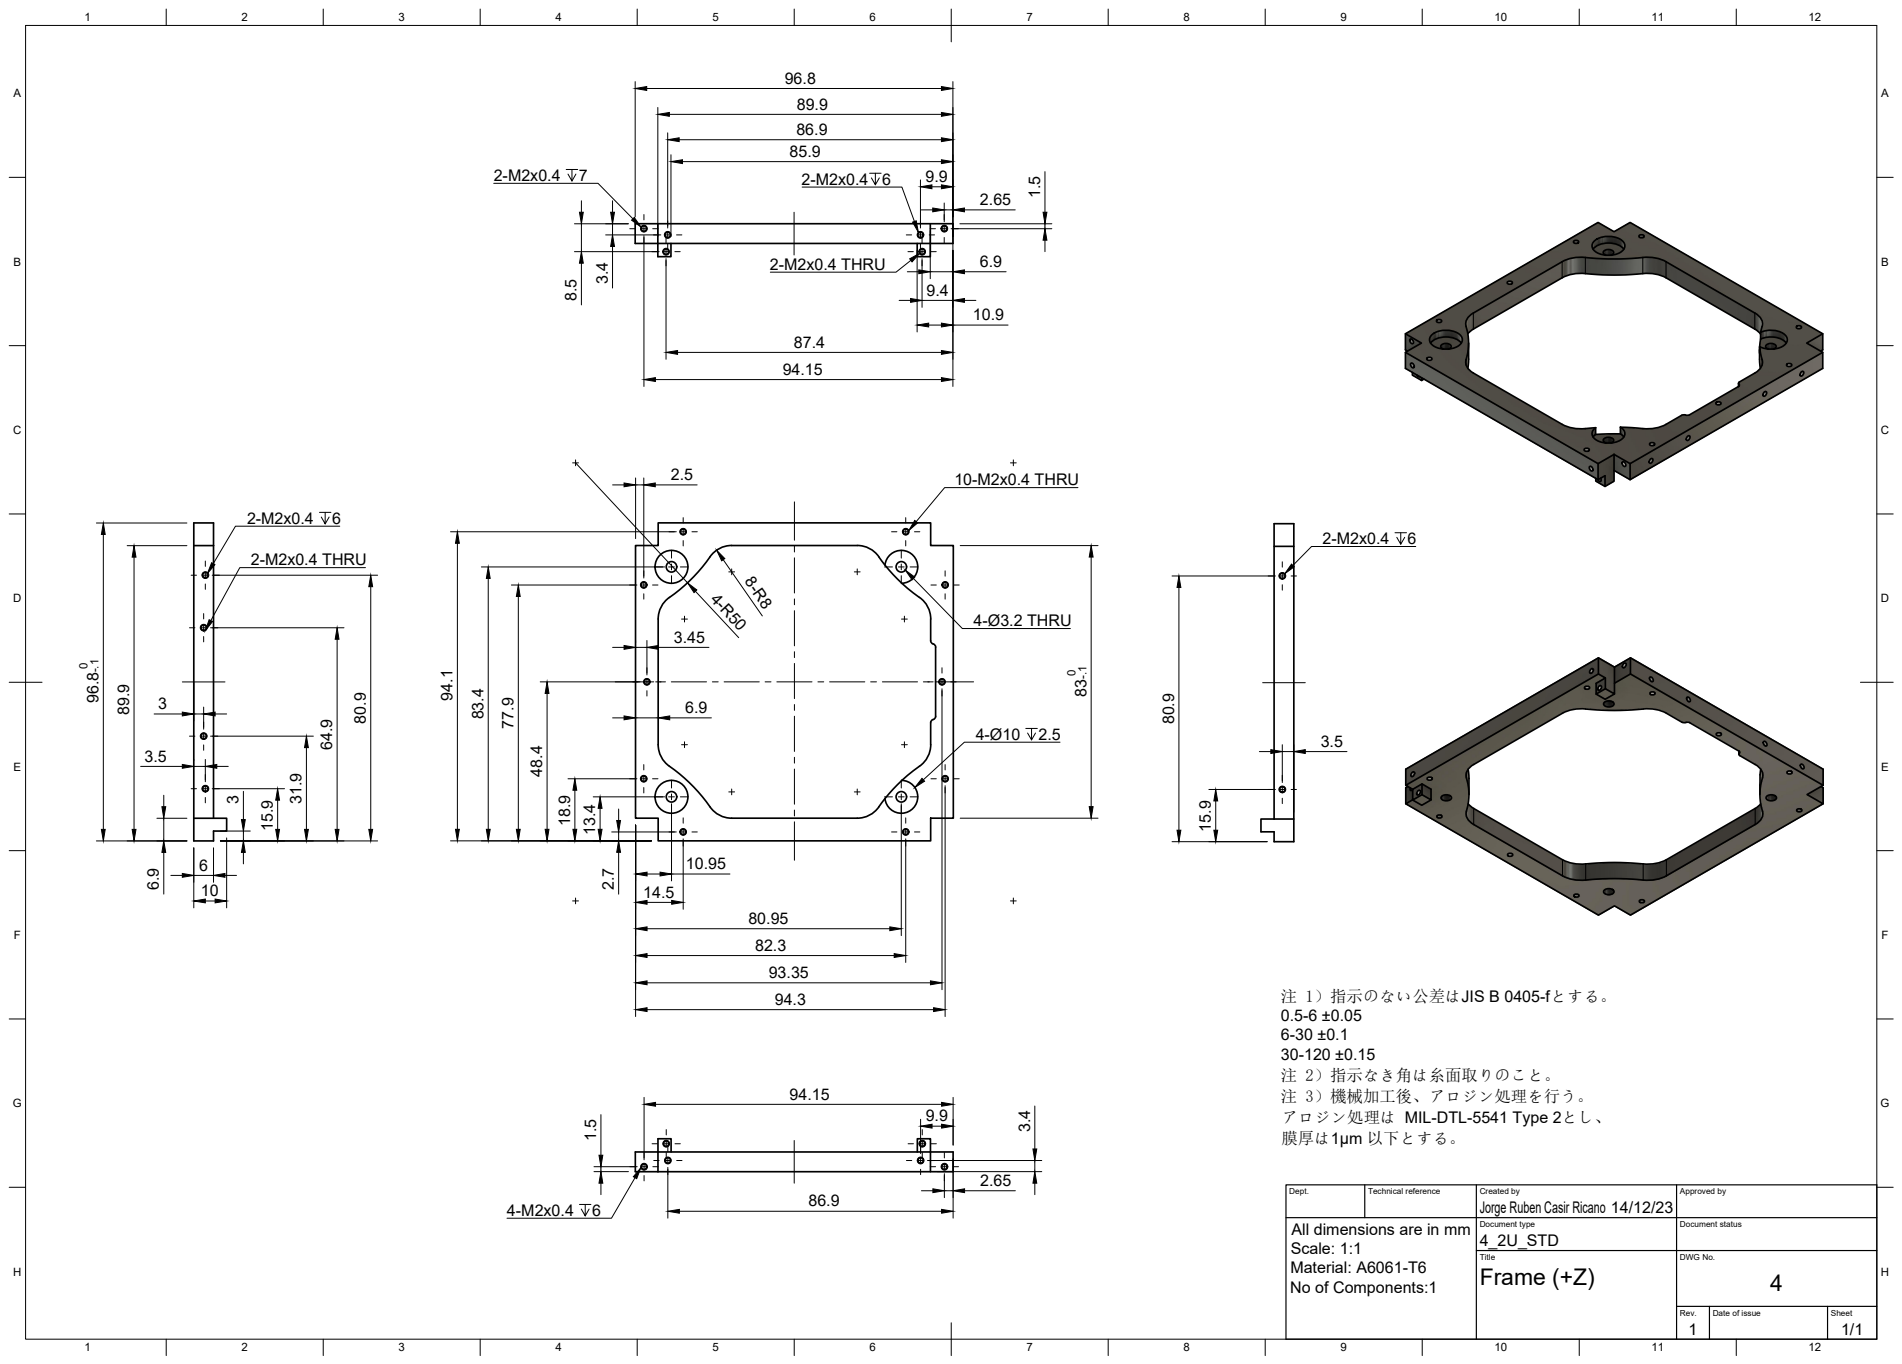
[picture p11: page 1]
10-M2x0.4 THRU; 4-Ø3.2 THRU; 2-M2x0.4 THRU; 注 1）指示のない公差はJIS B 0405-fとする。 0.5-6 ±0.05 6-30 ±0.1 30-120 ±0.15 注 2）指示なき角は糸面取りのこと。 注 3）機械加工後、アロジン処理を行う。 アロジン処理は MIL-DTL-5541 Type 2とし、; 膜厚は1μm 以下とする。 83 0-.1

Jorge Ruben Casir Ricano 2.7 13.4 18.9 48.4 77.9 83.494.1

Dept. | Technical reference | Created by 14/12/23 | Approved by

All dimensions are in mm Scale: 1:1 Material: A6061-T6 No of Components:1 | | Document type 4_2U_STD | Document status

Title Frame (+Z) | DWG No. 4

Rev. 1 | Date of issue | Sheet 1/1

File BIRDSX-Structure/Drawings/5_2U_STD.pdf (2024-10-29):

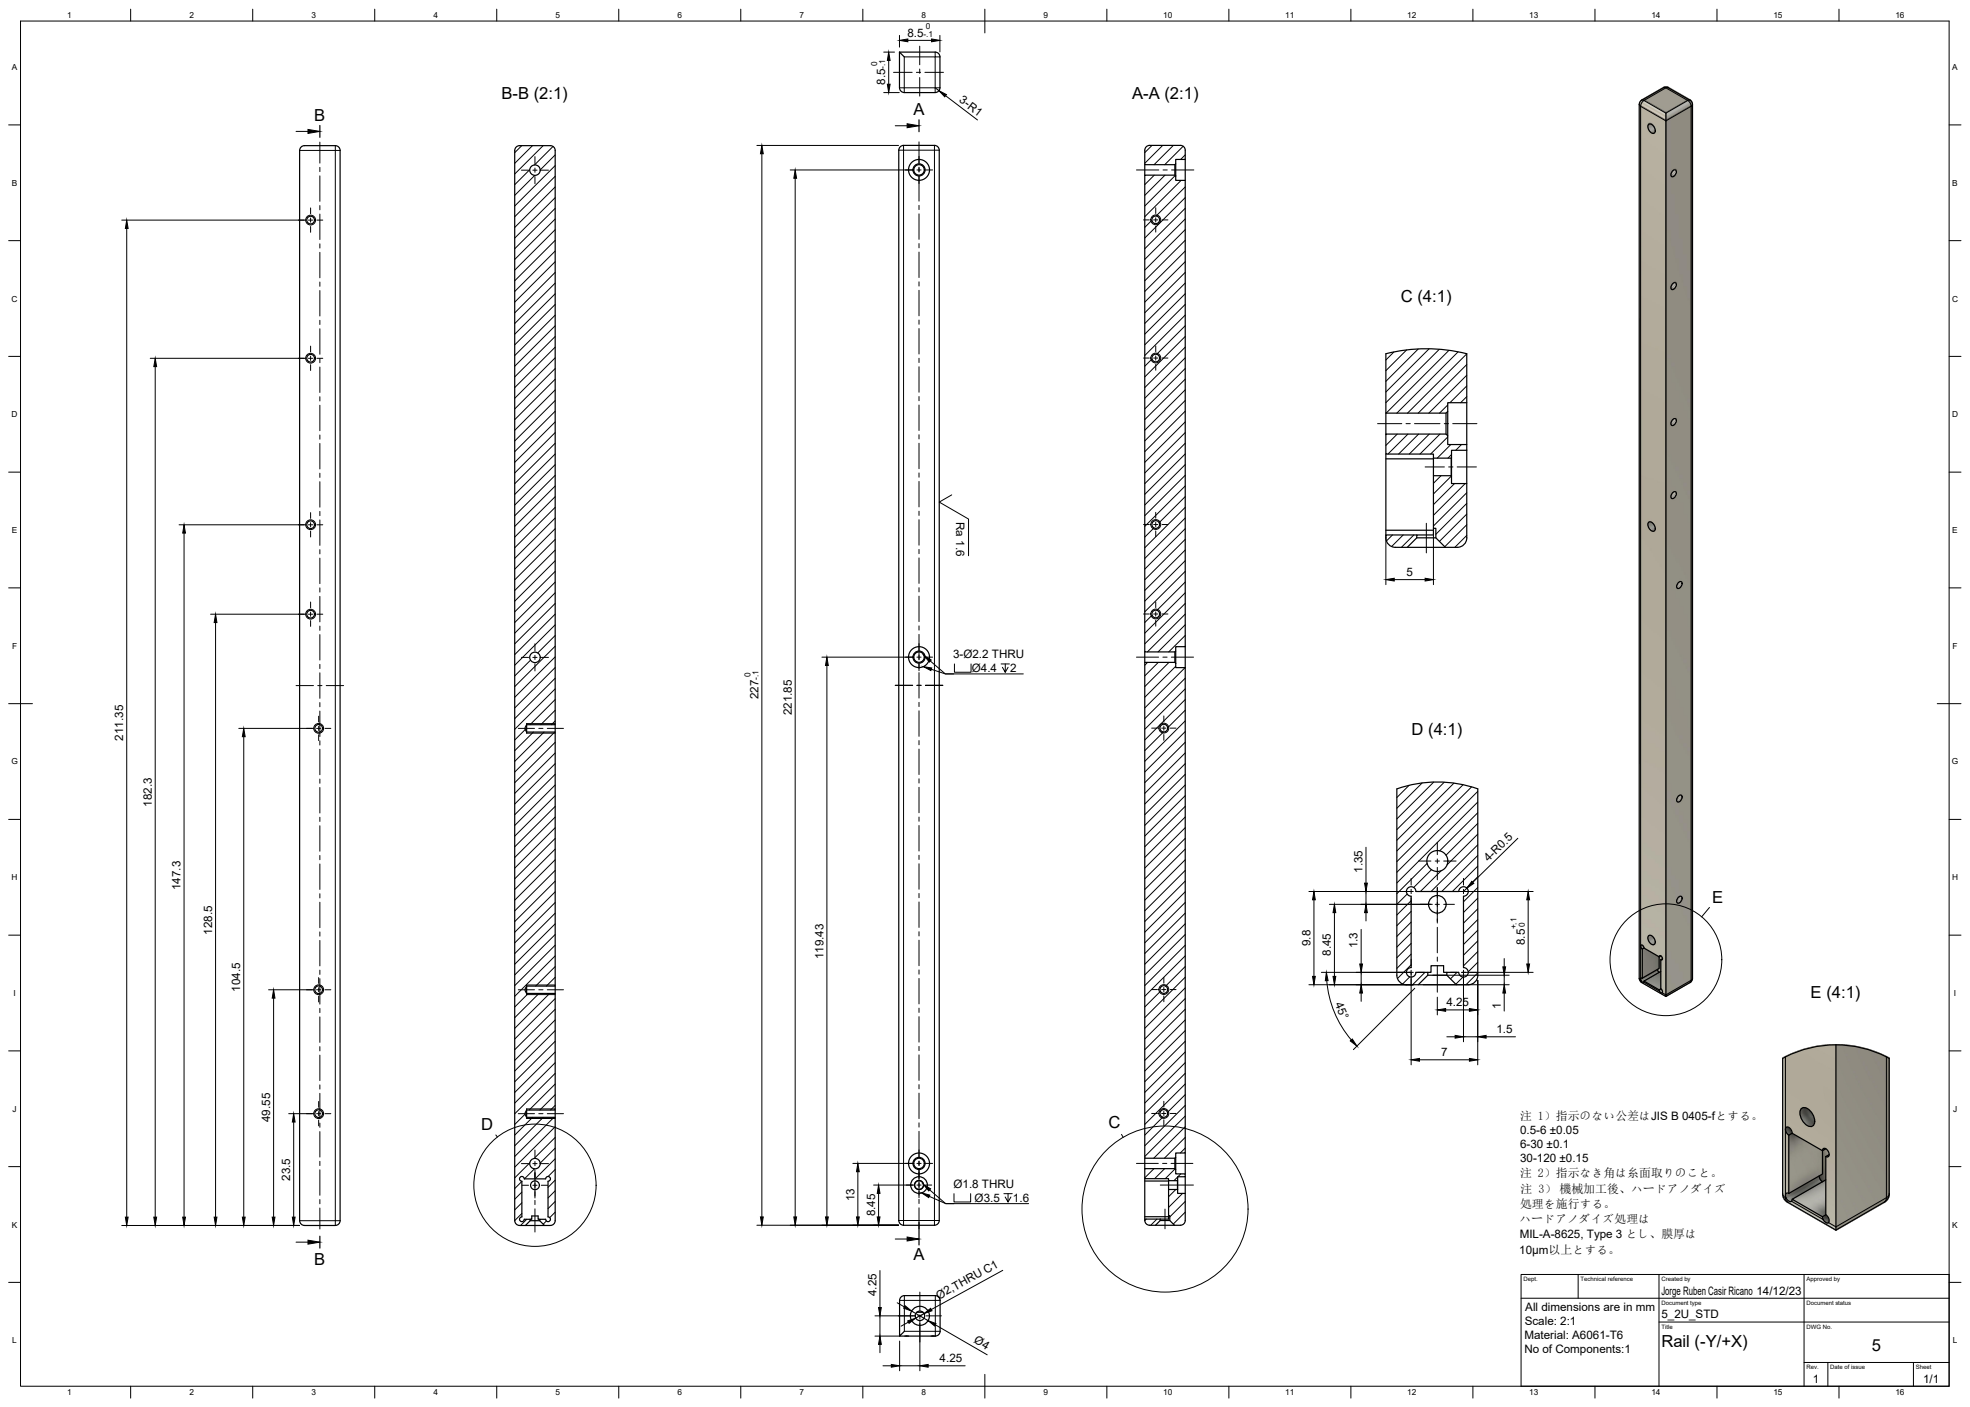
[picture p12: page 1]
Jorge Ruben Casir Ricano 1; 16 BACDEFGHIJKL; BACDEFGHIJKL 227 0-.1; 3-Ø2.2 THRU; Ø1.8 THRU; 1.6 Ø2,THRU C1; No of Components:1 8.4513 119.43 221.85; 注 1）指示のない公差はJIS B 0405-fとする。; 0.5-6 ±0.05 6-30 ±0.1 30-120 ±0.15 注 2）指示なき角は糸面取りのこと。 注 3） 機械加工後、ハードアノダイズ; 10μm以上とする。 8.5+.1 0 1.35

処理を施行する。
ハードアノダイズ処理は
MIL-A-8625, Type 3 とし、膜厚は

Dept. | Technical reference | Created by 14/12/23 | Approved by

All dimensions are in mm Scale: 2:1 Material: A6061-T6 | | Document type 5_2U_STD | Document status

Title Rail (-Y/+X) | DWG No. 5

Rev. | Date of issue | Sheet 1 1/1

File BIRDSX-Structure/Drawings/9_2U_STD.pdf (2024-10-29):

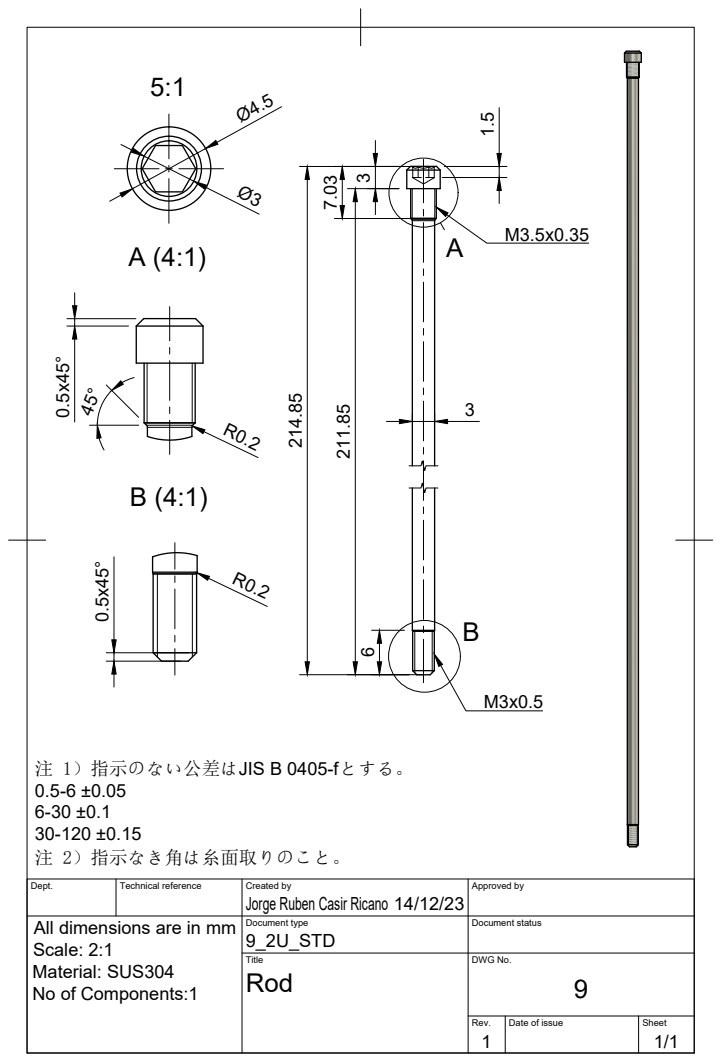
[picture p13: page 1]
注 1）指示のない公差はJIS B 0405-fとする。 0.5-6 ±0.05 6-30 ±0.1 30-120 ±0.15 注 2）指示なき角は糸面取りのこと。; No of Components:1

Jorge Ruben Casir Ricano 214.85

Dept. | Technical reference | Created by 14/12/23 | Approved by

All dimensions are in mm Scale: 2:1 Material: SUS304 | | Document type 9_2U_STD | Document status

Title Rod | DWG No. 9

Rev. 1 | Date of issue | Sheet 1/1

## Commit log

2024-10-29 Create CAD
2024-10-29 change order of folders
    [0_2U_STD.step, 1_2U_STD.step, 2_2U_STD.step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]
